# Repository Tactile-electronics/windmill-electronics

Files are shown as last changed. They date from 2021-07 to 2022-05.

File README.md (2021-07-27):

I can't work out how to do the two circuits on one board with the connections that you can add and remove.  So I've made two separate boards.  

I wanted you to have alook before I wire it up on Kicad as at the moment I'm not sure if I've got it right and some connections seem wrong

e.g the connections out of the board that is in series  have been connected together on the pcb - by KICAD - do I need  to change it in the schematic or can I do that in the wiring?

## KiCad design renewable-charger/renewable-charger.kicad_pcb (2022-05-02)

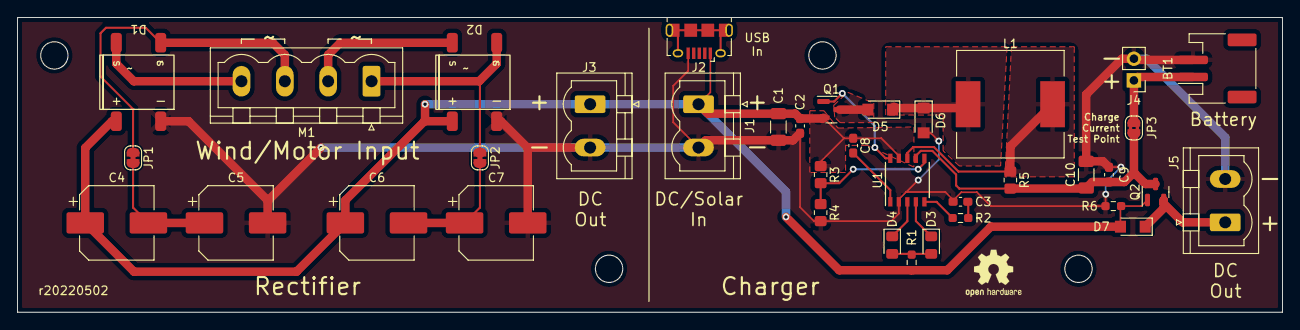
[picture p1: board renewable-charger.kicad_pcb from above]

Board: 2 copper layers, 148.2 x 34.5 mm, 37 parts (0 on the bottom side), 22 nets.

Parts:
BT1: Battery_Cell; JST_PH_S2B-PH-SM4-TB_1x02-1MP_P2.00mm_Horizontal
C1, C10: 10uF 50V; C_1206_3216Metric_Pad1.33x1.80mm_HandSolder
C2, C9: 1uF; C_0603_1608Metric_Pad1.08x0.95mm_HandSolder
C3: 220nF; C_0603_1608Metric_Pad1.08x0.95mm_HandSolder
C4, C5, C6, C7: C_Polarized_Small; CP_Elec_8x10.5
C8: 0.1uF; C_0603_1608Metric_Pad1.08x0.95mm_HandSolder
D1, D2: D_Bridge_+-AA; BridgeRectifier_DBLS
D3: LED Green; LED_0805_2012Metric_Pad1.15x1.40mm_HandSolder
D4: LED Red; LED_0805_2012Metric_Pad1.15x1.40mm_HandSolder
D5, D6, D7: D_Schottky; D_SMF
J1: Solar Input; PhoenixContact_MSTBVA_2,5_2-G-5,08_1x02_P5.08mm_Vertical
J2: USB_B_Micro; USB_Micro-B_Amphenol_10118194_Horizontal
J3: Wind Output; PhoenixContact_MSTBVA_2,5_2-G-5,08_1x02_P5.08mm_Vertical
J4: Battery; PinHeader_1x02_P2.54mm_Vertical
J5: Output; PhoenixContact_MSTBVA_2,5_2-G-5,08_1x02_P5.08mm_Vertical
JP1, JP2: SolderJumper_2_Bridged; SolderJumper-2_P1.3mm_Bridged_RoundedPad1.0x1.5mm
JP3: Test Point; SolderJumper-2_P1.3mm_Bridged2Bar_RoundedPad1.0x1.5mm
L1: 100uH 2.5A; L_12x12mm_H6mm
M1: Stepper_Motor_bipolar; PhoenixContact_MSTBVA_2,5_4-G-5,08_1x04_P5.08mm_Vertical
Q1, Q2: P-channel 30V 4A MOSfet; SOT-23
R1, R6: R_Small; R_0603_1608Metric_Pad0.98x0.95mm_HandSolder
R2: 120R; R_0603_1608Metric_Pad0.98x0.95mm_HandSolder
R3, R4: R_Small; R_0805_2012Metric_Pad1.20x1.40mm_HandSolder
R5: Rcs; R_0805_2012Metric_Pad1.20x1.40mm_HandSolder
U1: CN3791; SSOP-10_3.9x4.9mm_P1.00mm

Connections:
/Power +: C1.1, C2.1, C4.1, C6.1, C8.1, D1.1 (+), D2.1 (+), D7.2 (A), J1.1, J2.1 (VBUS), J3.1, Q1.2 (S), Q2.1 (G), R1.1, R3.1, R6.1, U1.9 (VCC)
/Power -: BT1.2 (-), C1.2, C2.2, C3.2, C5.2, C7.2, C9.2, C10.2, D1.2 (-), D2.2 (-), D6.2 (A), J1.2, J2.5 (GND), J3.2, J4.2, J5.2, R4.2, R6.2, U1.2 (GND)
unnamed: BT1.1 (+), J4.1, JP3.2 (B)
unnamed: C3.1, R2.2
unnamed: D1.3, M1.4
unnamed: D3.2 (A), D4.2 (A), R1.2
unnamed: D3.1 (K), U1.4 (DONE)
unnamed: D4.1 (K), U1.3 (CHRG)
unnamed: D5.2 (A), Q1.3 (D)
unnamed: D5.1 (K), D6.1 (K), L1.1
unnamed: D7.1 (K), J5.1, Q2.2 (S)
unnamed: D1.4, JP1.1 (A), M1.3
unnamed: C4.2, C5.1, JP1.2 (B)
unnamed: D2.4, JP2.1 (A), M1.1
unnamed: C6.2, C7.1, JP2.2 (B)
unnamed: C9.1, C10.1, JP3.1 (A), Q2.3 (D), R5.2, U1.7 (BAT)
unnamed: D2.3, M1.2 (-)
unnamed: Q1.1 (G), U1.10 (DRV)
unnamed: R2.1, U1.5 (COM)
unnamed: L1.2, R5.1, U1.8 (CSP)
unnamed: R3.2, R4.1, U1.6 (MPPT)
unnamed: C8.2, U1.1 (VG)

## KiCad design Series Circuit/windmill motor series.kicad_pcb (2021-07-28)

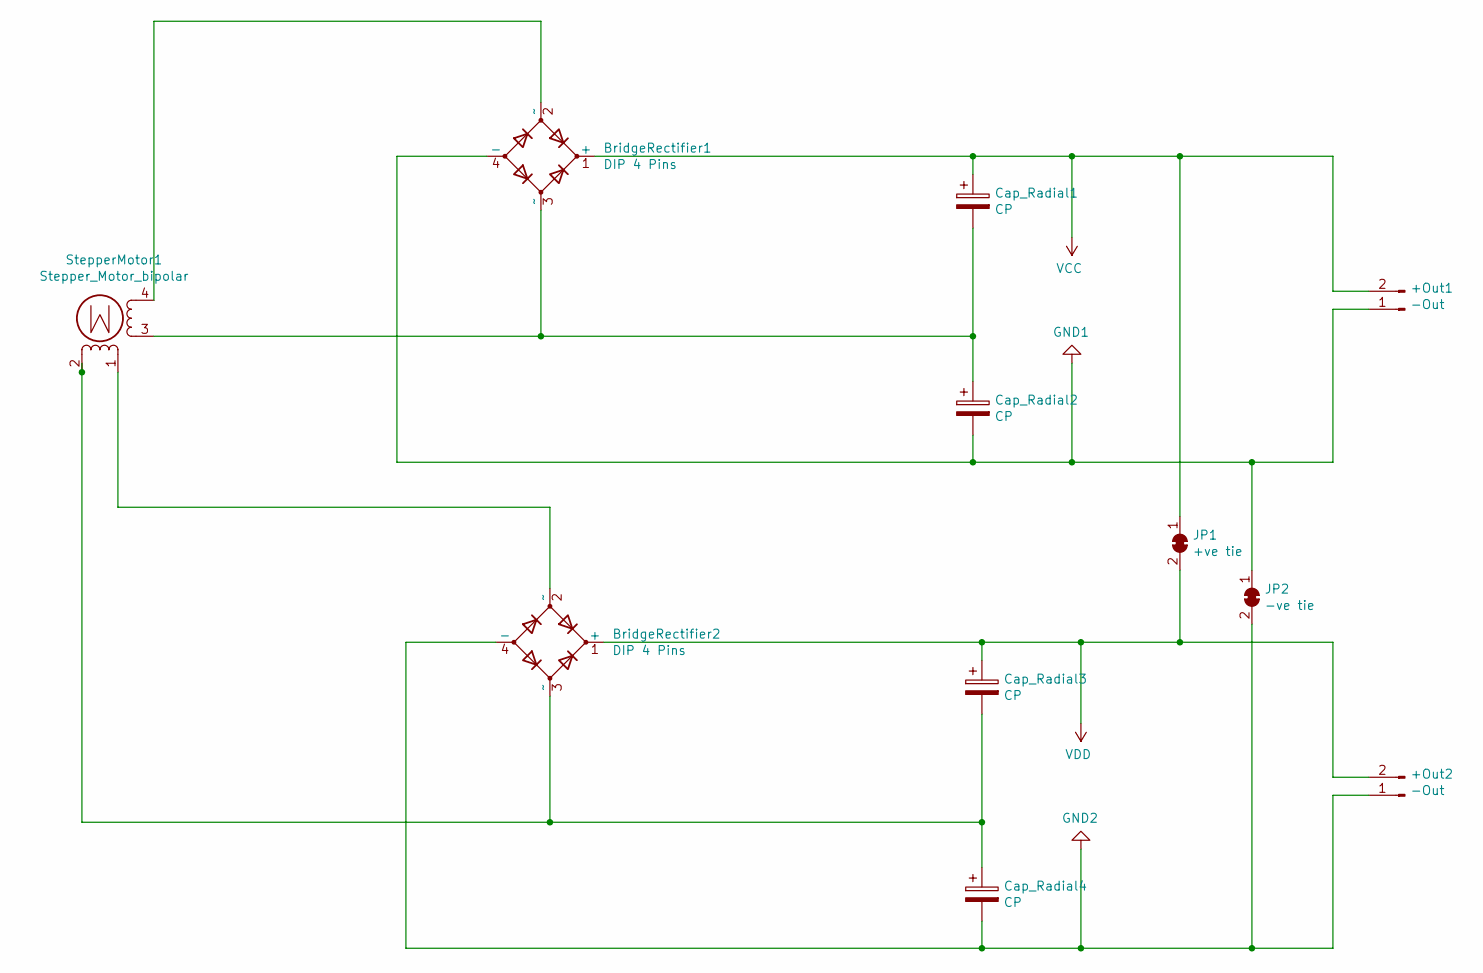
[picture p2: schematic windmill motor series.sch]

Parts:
+Out1, +Out2: -Out; WAGO_734_2pin_Straight_RuggedPads
BridgeRectifier1, BridgeRectifier2: DIP 4 Pins; Diode_Bridge_DIP-4_W7.62mm_P5.08mm
Cap_Radial1, Cap_Radial2, Cap_Radial3, Cap_Radial4: CP; CP_Radial_Tantal_D8.0mm_P5.00mm
JP1: +ve tie; SolderJumper-2_P1.3mm_Bridged_RoundedPad1.0x1.5mm
JP2: -ve tie; SolderJumper-2_P1.3mm_Bridged_RoundedPad1.0x1.5mm
StepperMotor1: Stepper_Motor_bipolar; TE_MATE-N-LOK_350211-1_1x04_P5.08mm_Vertical

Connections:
GND1: +Out1.1, BridgeRectifier1.4 (-), Cap_Radial2.2, JP2.1 (A)
GND2: +Out2.1, BridgeRectifier2.4 (-), Cap_Radial4.2, JP2.2 (B)
unnamed: BridgeRectifier1.2 (~~), StepperMotor1.4
unnamed: BridgeRectifier1.3 (~~), Cap_Radial1.2, Cap_Radial2.1, StepperMotor1.3
unnamed: BridgeRectifier2.2 (~~), StepperMotor1.1
unnamed: BridgeRectifier2.3 (~~), Cap_Radial3.2, Cap_Radial4.1, StepperMotor1.2 (-)
VCC: +Out1.2, BridgeRectifier1.1 (+), Cap_Radial1.1, JP1.1 (A)
VDD: +Out2.2, BridgeRectifier2.1 (+), Cap_Radial3.1, JP1.2 (B)

Board: 2 copper layers, 11 parts (0 on the bottom side), 8 nets, no tracks yet.

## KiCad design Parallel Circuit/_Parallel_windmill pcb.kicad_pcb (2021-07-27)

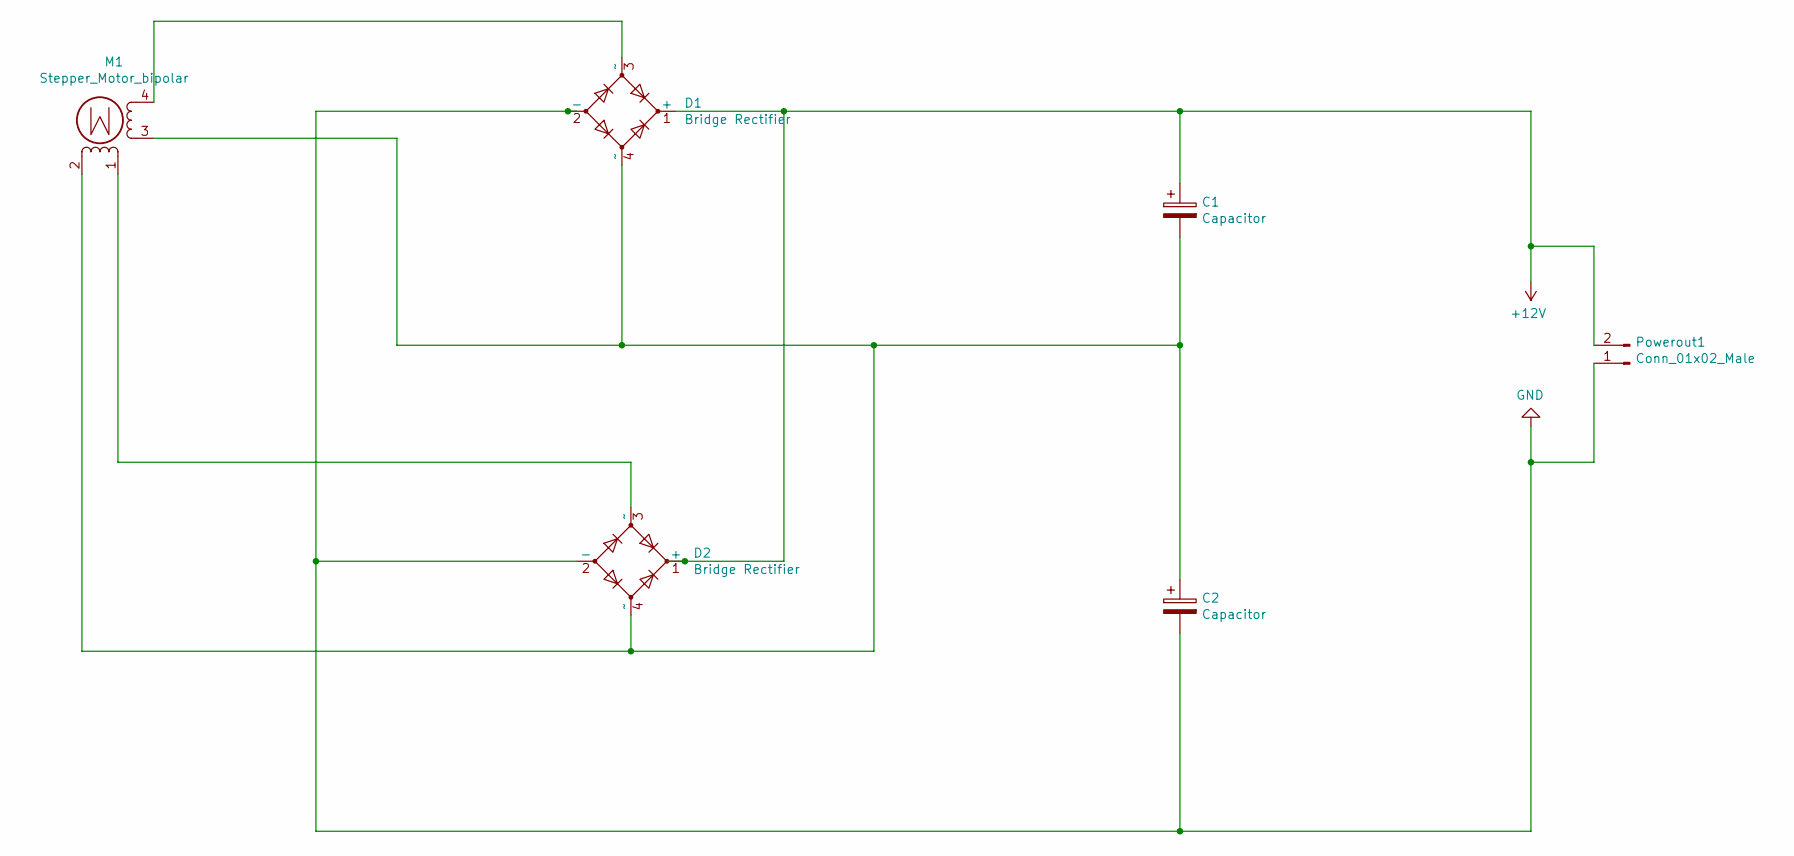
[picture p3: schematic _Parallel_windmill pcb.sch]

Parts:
C1, C2: Capacitor; CP_Radial_D8.0mm_P5.00mm
D1, D2: Bridge Rectifier; Diode_Bridge_DIP-4_W7.62mm_P5.08mm
M1: Stepper_Motor_bipolar; TE_MATE-N-LOK_350211-1_1x04_P5.08mm_Vertical
Powerout1: Conn_01x02_Male; WAGO_734_2pin_Straight_RuggedPads

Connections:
+12V: C1.1, D1.1 (+), D2.1 (+), Powerout1.2
GND: C2.2, D1.2 (-), D2.2 (-), Powerout1.1
unnamed: C1.2, C2.1, D1.4 (~~), D2.4 (~~), M1.2 (-), M1.3
unnamed: D1.3 (~~), M1.4
unnamed: D2.3 (~~), M1.1

Board: 2 copper layers, 6 parts (0 on the bottom side), 5 nets, no tracks yet.

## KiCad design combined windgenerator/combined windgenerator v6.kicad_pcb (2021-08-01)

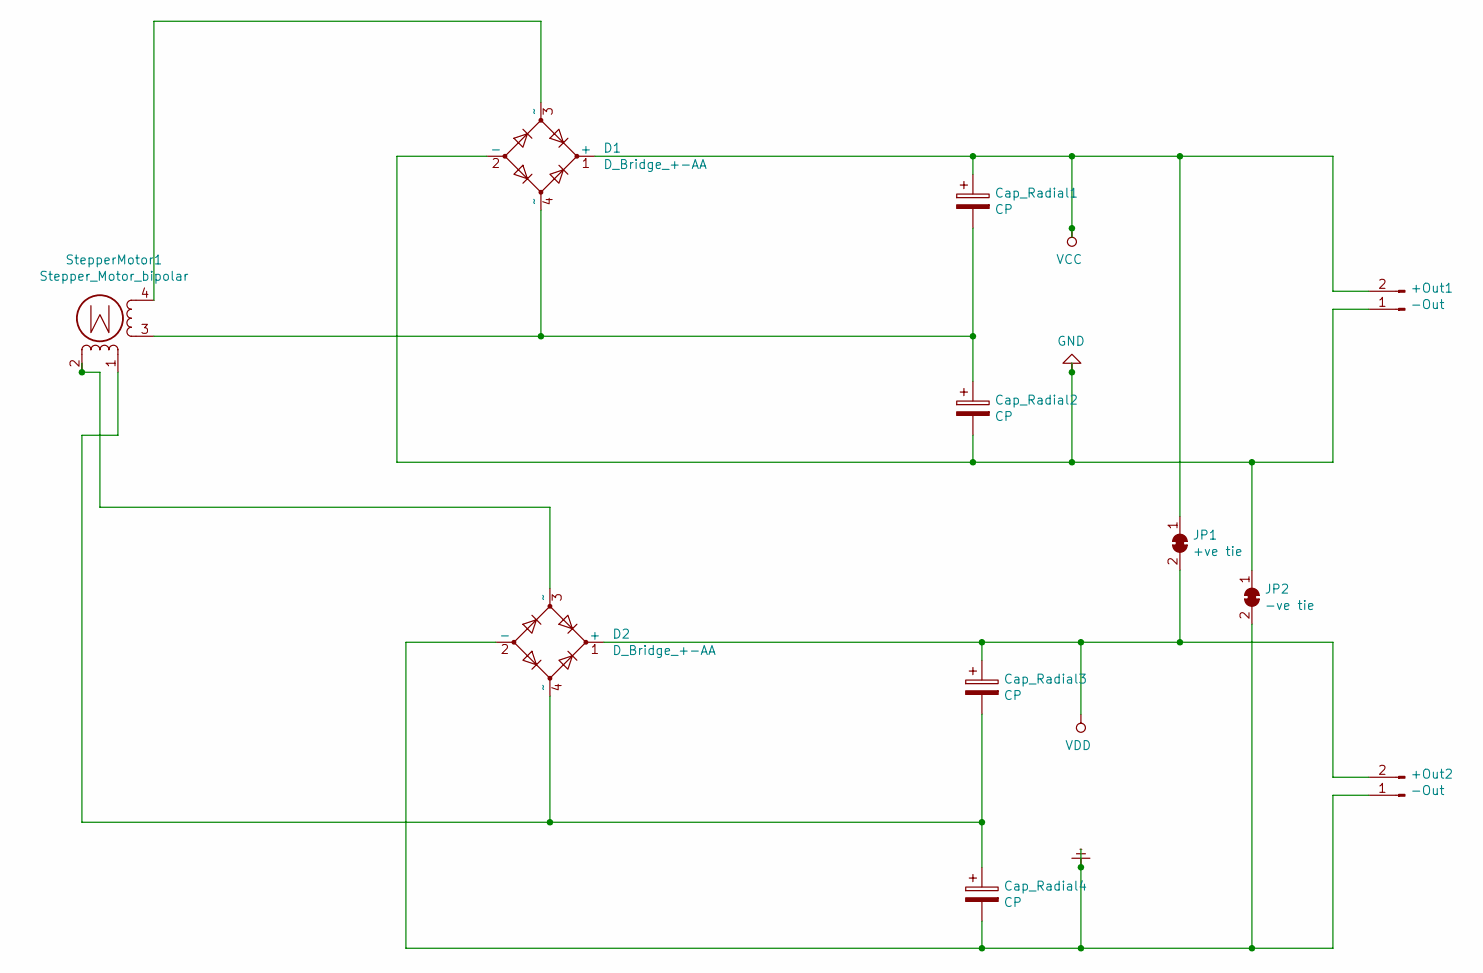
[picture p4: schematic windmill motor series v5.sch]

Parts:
+Out1, +Out2: -Out; WAGO_734_2pin_Straight_RuggedPads
Cap_Radial1, Cap_Radial2, Cap_Radial3, Cap_Radial4: CP; CP_Radial_Tantal_D8.0mm_P5.00mm
D1, D2: D_Bridge_+-AA; Diode_Bridge_DIP-4_W7.62mm_P5.08mm
JP1: +ve tie; SolderJumper-2_P1.3mm_Bridged_RoundedPad1.0x1.5mm
JP2: -ve tie; SolderJumper-2_P1.3mm_Bridged_RoundedPad1.0x1.5mm
StepperMotor1: Stepper_Motor_bipolar; TE_MATE-N-LOK_350211-1_1x04_P5.08mm_Vertical

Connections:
Earth: +Out2.1, Cap_Radial4.2, D2.2 (-), JP2.2 (B)
GND: +Out1.1, Cap_Radial2.2, D1.2 (-), JP2.1 (A)
unnamed: Cap_Radial1.2, Cap_Radial2.1, D1.4 (~~), StepperMotor1.3
unnamed: Cap_Radial3.2, Cap_Radial4.1, D2.4 (~~), StepperMotor1.1
unnamed: D1.3 (~~), StepperMotor1.4
unnamed: D2.3 (~~), StepperMotor1.2 (-)
VCC: +Out1.2, Cap_Radial1.1, D1.1 (+), JP1.1 (A)
VDD: +Out2.2, Cap_Radial3.1, D2.1 (+), JP1.2 (B)

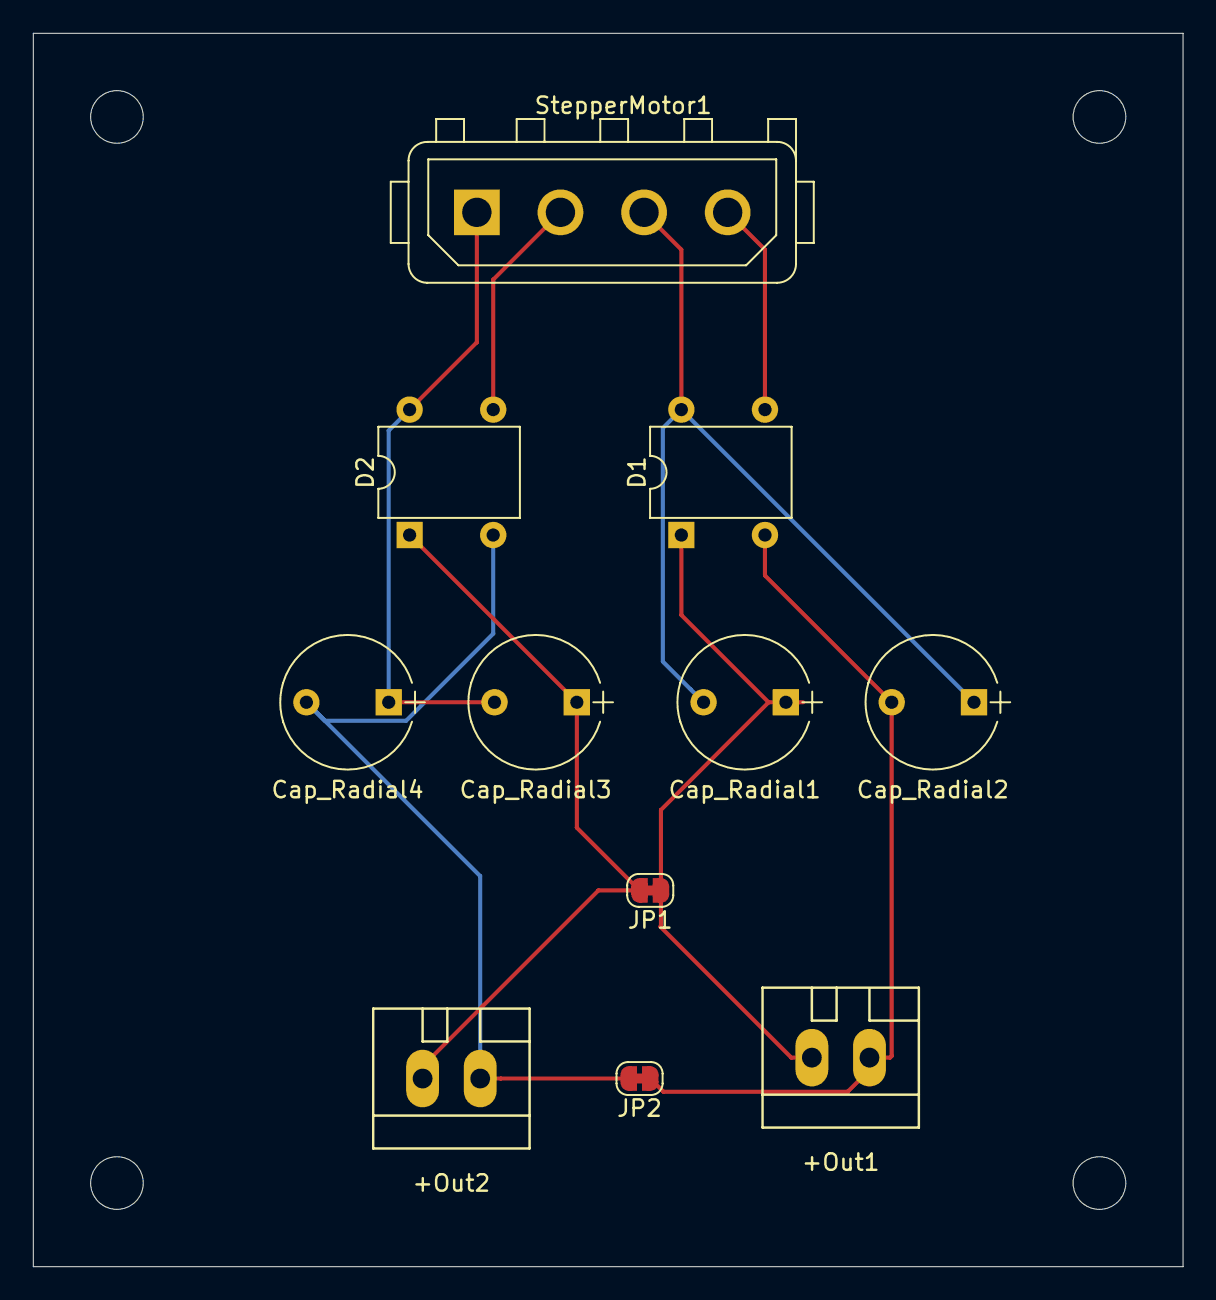
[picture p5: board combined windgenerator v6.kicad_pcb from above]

Board: 2 copper layers, 69.8 x 74.9 mm, 11 parts (0 on the bottom side), 8 nets.

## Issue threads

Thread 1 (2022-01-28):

Charging options

amcewen, 2022-01-28:
It would be useful to have the option to use batteries to smooth out/store the power harvested from wind or solar.

Li-Ion (18650 cells) and/or LiPo seem the most sensible battery options, which would give 3.7-4.1V and are available in various sizes.  The cheap garden solar lights use Ni-MH, but they're only 1.2V so would need to be run in series to get to useful voltages...

Input voltages that allow (the seemingly more common) 6V solar panels, and potentially higher voltages from stepper motors (with a voltage doubler circuit the steppers we've been using were getting up to 19V...) would be good.

Tactile-electronics, 2022-02-01:
Ah ok this makes a lot of sense - are there any charging / balancing issues with  the Li-Ion (18650 cells) type of batteries?
Can't it get dodgy with LiPo batteries - or has this been blown out of proportion?

amcewen, 2022-02-01:
There don't seem to be balancing issues, at least not that we've encountered using multiple 18650 cells in parallel at Aeternum or for the My Bike's Got LED boards.

You do need to be careful not to overcharge or over discharge LiPo and Li-Ion batteries, but we'd include a protection chip in the circuit (I've got that on the My Bike's Got LED board) to disconnect the battery if that happens.

I've been looking at possible options... got a few Texas Instruments chips and another that we use at Aeternum to add to this—will draw up a table tomorrow so we can compare them.

CN3063.  $0.743 each.  Input voltage 4.4V-6V.  Mentions solar as a potential input.

Actually, the manufacturer of that chip has an assortment of possible options - http://www.consonance-elec.com/product-E-Solar%20Charge%20Management.html - from around $0..40 from LCSC.com.  The CN3722, CN3165, CN3163 and CN3791 seem worth a closer look.

Some other modules I've found on LCSC, probably not as useful as the Consonance modules...

[LP4060S](https://www.lcsc.com/product-detail/Battery-Management-ICs_LOWPOWER-LP4060SB5F_C517260.html) $0.0509.  Input voltage 3.9-6V (with 8V as absolute max rating).  No mention of solar, seemingly intended more for USB charging

[RY4054](https://www.lcsc.com/product-detail/Battery-Management-ICs_RYCHIP-Semiconductor-Inc-RY4054AT5_C910135.html) $0.0746.  4.25-6.5V (max of 10V).  No mention of solar

[SE9019](https://www.lcsc.com/product-detail/Battery-Management-ICs_Seaward-Elec-SE9019_C415995.html) $0.487 4.7-5.5V (max of 6.5V) Mentions MPPT, so presumably is solar-compatible, but the datasheet is in Chinese, so  tricky  to know how to use fully.

LCSC seem to have a bunch of (what I suspect are) TP4056-compatible chips, for around $0.10 each.  Might be worth trying the board I've got here to see how it copes with solar or wind...

amcewen, 2022-02-02:
Finding chips with solar provision seems to be the trickiest part.

| Chip | Low voltage | High voltage | Price |
|---|---|---|---|
| [AEM10941](https://e-peas.com/product/aem10941/) | 0.05V | 5V | £3.95+vat |
| [BQ24210](https://www.ti.com/lit/ds/symlink/bq24210.pdf?ts=1643621020813&ref_url=https%253A%252F%252Fjlcpcb.com%252F) | 3.5V | 7V (max 18V) | £2.19 |
| [CN3063](http://www.consonance-elec.com/seriesCN3063-E.html#Application_Note%EF%BC%9A) | 4.4V | 6V | $0.743 |
| [CN3163](http://www.consonance-elec.com/seriesCN3163-E.html) | 4.4V | 6V | $0.416 |
| [CN3722](http://www.consonance-elec.com/seriesCN3722-E.html) | 7.5V | 28V | $1.48 |
| [CN3165](http://www.consonance-elec.com/seriesCN3165-E.html) | 4.4V | 6V | $0.474 |
| [CN3791](http://www.consonance-elec.com/seriesCN3791-E.html) | 4.5V | 28V | $0.669 |
| [SE9019](https://www.lcsc.com/product-detail/Battery-Management-ICs_Seaward-Elec-SE9019_C415995.html) | 4.7V | 5.5V | $0.49 |

The first two are probably good if we were just using small solar panels or USB power.  They're not as useful for wind power (I think) and are pretty expensive compared to the other options.

The CN3791 looks like the best choice, although that requires a few more components around it than the others.  The low end of the voltage range would ideally be a bit lower, but the issue then is that you'd need some sort of boost circuit to get the voltage above the battery voltage, so I think that's why something just above 4.2V is so common.

Tactile-electronics, 2022-02-08:
Ok - so does the voltage in need to be above 4.5V?
So would a boost circuit be before or after the chip?
this is more complex so trying to get my head around it.
is it possible to boost before the chip if needed and after the chip too to for circuits that need a higher voltage?

amcewen, 2022-02-20:
Okay (for an initial test board at least) we're going to go with the CN3791.  Spinning designing the circuit for that out as its own issue — #2

Closed 2022-02-20.

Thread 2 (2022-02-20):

Design circuit for CN3791 charging chip

amcewen, 2022-02-20:
Lay out the schematic for the charging part of the circuit

amcewen, 2022-02-20:
Notes from reading through the datasheet...

> the charge current is set by the external sense resistor RCS and an internal 120mV reference, the charge current equals to 120mV/RCS

We need to decide what current we should (at a maximum) charge the battery at.  There are recommendations based on the size of the battery, so it'll probably be a component that gets tuned based on the size of battery it's likely to use.  Once we've chosen the likely charge current we can work out the inductor to use — need to check the datasheet again for details of that.

Not quite sure how to choose the MPPT voltage (the Maximum Power Point Tracking, which tries to optimise the power from the solar panel).  However, once we work it out...

> The maximum power point voltage is decided by the following equation:
> V<sub>MPPT</sub> ＝1.205×(1＋R3／R4)

We'll need to add...
> P-channel MOSFET with Rds(on) in the range of 30mΩ

Diodes should handle the expected current, but shouldn't be *lots* over that, as that'll lose some efficiency.

We could (see Fig 3 in the datasheet) switch out D1 and use another MOSfet for a bit more efficiency, but that'll be a bit more expensive (MOSfet, capacitor and resistor instead of a single diode)

amcewen, 2022-03-23:
Apart from setting the Vmppt value, which I've spun out as #3, the schematic is done with the components all chosen.  Next step is to start arranging the actual PCB.

Closed 2022-03-23.

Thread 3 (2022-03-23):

Choose MPPT voltage

amcewen, 2022-03-23:
The voltage for the MPPT (maximum power point tracking) for the solar panel is set with a voltage divider of `R3` and `R4`.  We'll need to choose suitable values for that to set the voltage.

From the [datasheet](http://www.consonance-elec.com/pdf/datasheet/DSE-CN3791.pdf):
> The maximum power point voltage is decided by the following equation:
>     Vmppt = 1.205 x (1 + R3 / R4)

amcewen, 2022-05-18:
I'm still not sure what's best for the MPPT voltage.  Looking at [this solar harvesting board I've used in the past](https://www.tindie.com/products/jaspersikken/solar-harvesting-into-li-ion-battery/) for an example, that's set to 70% of the open circuit voltage of the panel.

Now, we don't know what panels we're likely to use, but I do have a 12V panel here I can try, and 6V panels are also quite common, so as a start I'll get some resistors for 70% of either of those voltages.

Reworking that equation we get that R3/R4 = (0.7*Voc)/1.205 - 1.  So for a 12V panel R3/R4 = 5.97; and for a 6V panel R3/R4 = 2.485.  Mapping very roughly onto more common resistor values, if we get some 330ohm, 1K and 2K, we can see how that fares.

huffeec, 2022-07-20:
On the test boards we made up today R3=2K R4=330 which gives R3/R4 ~ 6

amcewen, 2022-08-26:
Reading [this article on MPPT](https://hackaday.com/2022/08/03/maximum-power-point-tracking-optimizing-solar-panels/) I wonder if the capacitors to smooth the wind output are (a) getting in the way of the chip working out the right solar power to track the maximum power point, and (b) if they'd even be needed for the wind power either.

Could be worth some tests in #12 with the capacitors removed.

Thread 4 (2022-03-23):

Lay out PCB

amcewen, 2022-03-23:
Following on from #2, we need to work out the physical layout for the circuit.

amcewen, 2022-04-24:
Board laid out, including copper fill zones round the parts of the charging circuit that might get warmer.  Added some mounting holes too.

Just needs some extra labels now:
* To mark inputs / outputs
* Explain jumpers (where possible)
* Add a revision number
* Add a link to this repo (plus https://tactile-electronics.tumblr.com/ and mcqn.com/ibal233)
* Add RoHS, WEEE logos
* Add OSHW logo

amcewen, 2022-05-02:
I've finished (I think) the silkscreen labels.  Any tweaks/suggestions/etc. @Tactile-electronics, before I send off for a handful (half-a-dozen?  A dozen?) to get fabbed for testing?

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

Tactile-electronics, 2022-05-03:
Oh wow ,  brilliant! I’m really excited to try them out. I would imagine
there’s not a huge amount of difference price wise so a dozen?
Is it easier for you to order them and me pay you back or the other way
around?
Thanks
Laura
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

amcewen, 2022-05-05:
Great.  I've ordered 15 from JLC, and most of the parts — still need to get the bridge rectifiers and resistors (and connectors, but I'm not sure we'd want to populate them by default anyway) — from LCSC (needed to get the charger chips from there, so figured I'd order the other easy stuff at the same time)

About £60 so far (it's all in $) and half of that is postage :grin:  It'll be a couple of weeks before it arrives, I'll let you know when it gets here.

Closed 2022-05-05.

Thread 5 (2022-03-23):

Add switched output for the load

amcewen, 2022-03-23:
We shouldn't charge the battery at the same time as it's being used to power something; so we should add a mosfet to switch the battery output off when it's charging (and also use the supply to the charger to power the output at the same time)

amcewen, 2022-04-24:
Implemented the circuit from that application note, adding a p-channel mosfet (to switch the battery output on/off), a pull-down resistor and a diode (to prevent the battery output controlling the mosfet)

Closed 2022-04-24.

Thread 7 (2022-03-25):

Add an option for USB charging?

amcewen, 2022-03-25:
We could add the footprint for a micro-USB connector, which would allow the board to be turned into a standard USB battery charger too.

USB-C would be a more futureproof option, but would also require a couple of extra resistors...

amcewen, 2022-04-03:
Given that USB isn't a key requirement, I've gone with the simpler option of just adding a micro-USB connector.

Closed 2022-04-03.

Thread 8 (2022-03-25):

Add test points so we can measure voltage and current

amcewen, 2022-03-25:
I've got some INA219 breakout boards which can monitor voltage and current.

To check the performance of the circuit (and any windmills or solar panels) it's be good to be able to monitor things at various points around the circuit:
* [x] between the rectifier circuit and the charger
* [x] between the solar connector and the charger
* [ ] between the charger and the battery

amcewen, 2022-04-03:
As there are two sets of connections between the rectifier and the charger — so the board can be cut there and become separate "windmill rectifier" and "charger", they can be used as test points too.  Similarly a solar connector to charger measurement can be done in the wiring from the solar panel.

We could do similar with the wiring for the battery, but given they've got JST plugs, it's handy to have a specific test point.  I've added that: `JP3`.  It's normally bridged, so will need to be cut if we want to test the current through it, and wires soldered to each side of the jumper.

Closed 2022-04-03.

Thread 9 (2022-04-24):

Apply for OSHWA certification?

amcewen, 2022-04-24:
Given it's open hardware, we should get the OSHWA certification for it. https://application.oshwa.org/apply

https://github.com/mcqn/my-babys-got-led/issues/9 shows the process we went through for the My Baby's Got LED certification.  It's pretty light-touch, the main thing that might be missing is some documentation for using the board.

Tactile-electronics, 2022-04-29:
Hi Adrian,
Thanks for all this, hopefully getting my head together a bit over the next
few weeks to catch up a bit with this!
Thanks
Laura

On Sun, 24 Apr 2022 at 21:39, Adrian McEwen ***@***.***>
wrote:

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

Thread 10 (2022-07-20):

Add values for R1,R5 and R6 to Kicad

huffeec, 2022-07-20:
Currently R1,R5 and R6 values are not defined in Kicad.
For the test boards today we used

R1 560 Ohm
R5 0.068
R6 10K

Tactile-electronics, 2022-07-20:
Thanks this is really helpful

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

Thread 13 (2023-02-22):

The charging LED stays on, regardless of charge level

amcewen, 2023-02-22:
I've been using it as a USB charger for a few months now, and while it works well, it never reports that charging is done.

I've had a 10500mAh Li-Ion battery on charge for five days solid, and it's still showing the "charging" LED.  I don't think the battery was especially discharged (might even have been fully charged) before I put it on to charge, and its sitting at 4.22V now so I think it *is* charged.

Obviously it would be better if the "done" LED on the charging circuit worked :grin:

huffeec, 2023-02-27:
The [data sheet](https://www.laskakit.cz/user/related_files/dse-cn3791-2.pdf) has a formula for the 'Full scale charge current' as a function of  Rcs (R5)

Ich = 120mV / Rcs

Charge termination is determined by: "In constant voltage mode, the charge current decreases gradually. When the charge current decreases to 16% of the full-scale current, the charging is terminated"

Under PCB layout considerations it recommends;
"(6) Place the charge current sense resistor RCS right next to the inductor output but oriented such that the IC’s CSP and BAT traces going to RCS are not long. The 2 traces need to be routed together as a single pair on the same layer at any given time with smallest trace spacing possible."

So it's possible that a modified trace, or different value for R5 could resolve this.

huffeec, 2023-03-13:
The original boards had Rcs as 0.068 ohm
Giving a charging current of 1760mA

[https://www.digikey.co.uk/en/maker/blogs/charging-lithium-ion-batteries](https://www.digikey.co.uk/en/maker/blogs/charging-lithium-ion-batteries) suggests a charge current of about half the capacity of the battery. So for the 13400mAh packs we get ~6700mA

So (I think) we should be aiming for Rcs of ~0.018 Ohm

I've made up a board with the closest we currently have to that. Two 0.068 stacked in parallel giving 0.034 ohms
It's charging so I'll see if this triggers the 'Done' light

huffeec, 2023-03-15:
Based on what was discovered in #12 the next step is to setup board C with a bench supply and measure current with one of the INA219 sensors.

huffeec, 2023-04-05:
Running an 8 hour test with board A gives this data for the changing current.
The Bus voltage was a fairly constant 3.11V for the whole period.

First thoughts are generally the values are much lower than I was expecting, and I can't really explain why the current is negative after 7hrs.

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

huffeec, 2023-04-17:
Test two with board A makes even less sense. This is a five hour series.
The starting battery voltage was 3.87V, bus voltage remains constant throughout.
I am starting to think the chip on this board is no longer working. The next test will be with board D
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

amcewen, 2023-08-30:
I've been wondering about this some more today.  No real progress, but...
* I wonder if it's worth trying the [CN3781 chip](http://www.consonance-elec.com/en/73.html) instead.  That requires a tiny change to the circuit, which I think could be tested with a modded version of the existing PCBs.
* Paul downstairs has a logic probe that can test for high impedance as well as voltage.  Might be worth confirming the state of the LED pins to check they match table 1 on page 7 of the CN3791 datasheet
* I wonder if a higher charge voltage (I'm assuming we've been mostly testing with USB voltages of 5V so far) would fix the problem (not a full fix, but to identify a possible issue)
* And/or running a test with the 12V solar panel I've got

Beyond that, maybe a different charger chip would be a solution (or the next step to try)?  Presumably something which can cope with an input voltage of ~12V (to allow 12V solar panels, which are quite common), but it might not need the 28V and up to 4A ratings of the existing chip - maybe the fact we're often at the lower-end of its design range is what's causing some of the trouble?

amcewen, 2023-11-02:
A couple more thoughts (courtesy of Paul H):
* check battery chemistry - is the charger chip designed for LiPo but we've been using Li-Ion batteries?
* check for leakage current on battery - is it pulling a bit still so the charger thinks things are still charging?  Maybe the protection circuit (or in reality, likely two protection circuits) is consuming a bit of power and the charger always thinks it's still charging.

I've bought a few of the CN3781 chips to try sometime too.

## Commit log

2021-07-27 Create pcb design
2021-07-28 Separate out power flags and add jumpers to allow tied operation.
    [windmill motor series.kicad_pcb, windmill motor series.sch]
2021-07-30 Create final pcb
2021-07-30 Create pcb
2021-08-01 Create pcbs
2022-02-20 Initial work on the charger schematic. Components and mosfet still needed. Part of #2
    [renewable-charger.kicad_pcb, renewable-charger.kicad_sch]
2022-03-21 Schematic almost finished—most components chosen with part numbers. Start made on PCB. Part of #2
    [renewable-charger.kicad_pcb, renewable-charger.kicad_sch]
2022-03-28 Add windmill rectifying voltage-doubler circuit to the schematic. Part of #6
    [renewable-charger.kicad_pcb, renewable-charger.kicad_sch]
2022-03-30 The windmill rectifier circuit is laid out on the PCB, apart from routing bits to the output connector, as its final location isn't set yet. Part of #6
    [renewable-charger.kicad_pcb, renewable-charger.kicad_sch]
2022-04-03 Tweaks to the rectifier circuit. Part of #6
    [renewable-charger.kicad_sch]
2022-04-03 Add test point to measure current into the battery. Implements #8
    [renewable-charger.kicad_pcb, renewable-charger.kicad_sch]
2022-04-03 Add micro-USB connector for USB charging. Implements #7
    [renewable-charger.kicad_pcb, renewable-charger.kicad_sch]
2022-04-04 Disconnect battery output when charging; add through-hole battery connector alternative. Part of #5
    [renewable-charger.kicad_sch]
2022-04-23 Reduce power trace thickness
    [renewable-charger.kicad_pcb]
2022-04-24 All connections wired on PCB. Still needs zones, final position for mounting holes and edges, and some labelling. Part of #4
    [renewable-charger.kicad_pcb, renewable-charger.kicad_sch]
2022-04-24 Added copper zones; positioned mounting holes and tidied up edge cuts. Just labels left. Part of #4
    [renewable-charger.kicad_pcb]
2022-05-02 Silkscreen additions for labelling, revision number, etc. added. Final part of #4
    [renewable-charger.kicad_pcb]
